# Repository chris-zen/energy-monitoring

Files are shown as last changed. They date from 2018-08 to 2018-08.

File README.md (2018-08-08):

# energy-monitoring

Source for my home's energy monitoring system

- [arduino](arduino) contains the firmware for an Arduino UNO board that samples voltage and intensity signals. Sampled data can be transferred to the computer through the USB port as a serial device.
- [python](python) contains Python code that knows how to read voltage and intensity data sampled with the Arduino board, how to filter and process the data to calculate Volts, Intensity and Power, and generate plots with [matplotlib](https://matplotlib.org/).
- [eagle](eagle) contains a hardware design for the final energy monitoring system, including the analog stages to prepare voltage and intensity signals to be sampled by the Arduino ADC (Unfinished).

# Blogs

* [My home energy monitoring vision](https://aloneinthehack.wordpress.com/2013/05/20/my-home-energy-monitoring-vision/)
* [First power measurements](https://aloneinthehack.wordpress.com/2013/04/27/first-power-measurements/)
* [Starting to explore OpenEnergyMonitor.org](https://aloneinthehack.wordpress.com/2013/04/07/starting-to-explore-openenergymonitor-org/)

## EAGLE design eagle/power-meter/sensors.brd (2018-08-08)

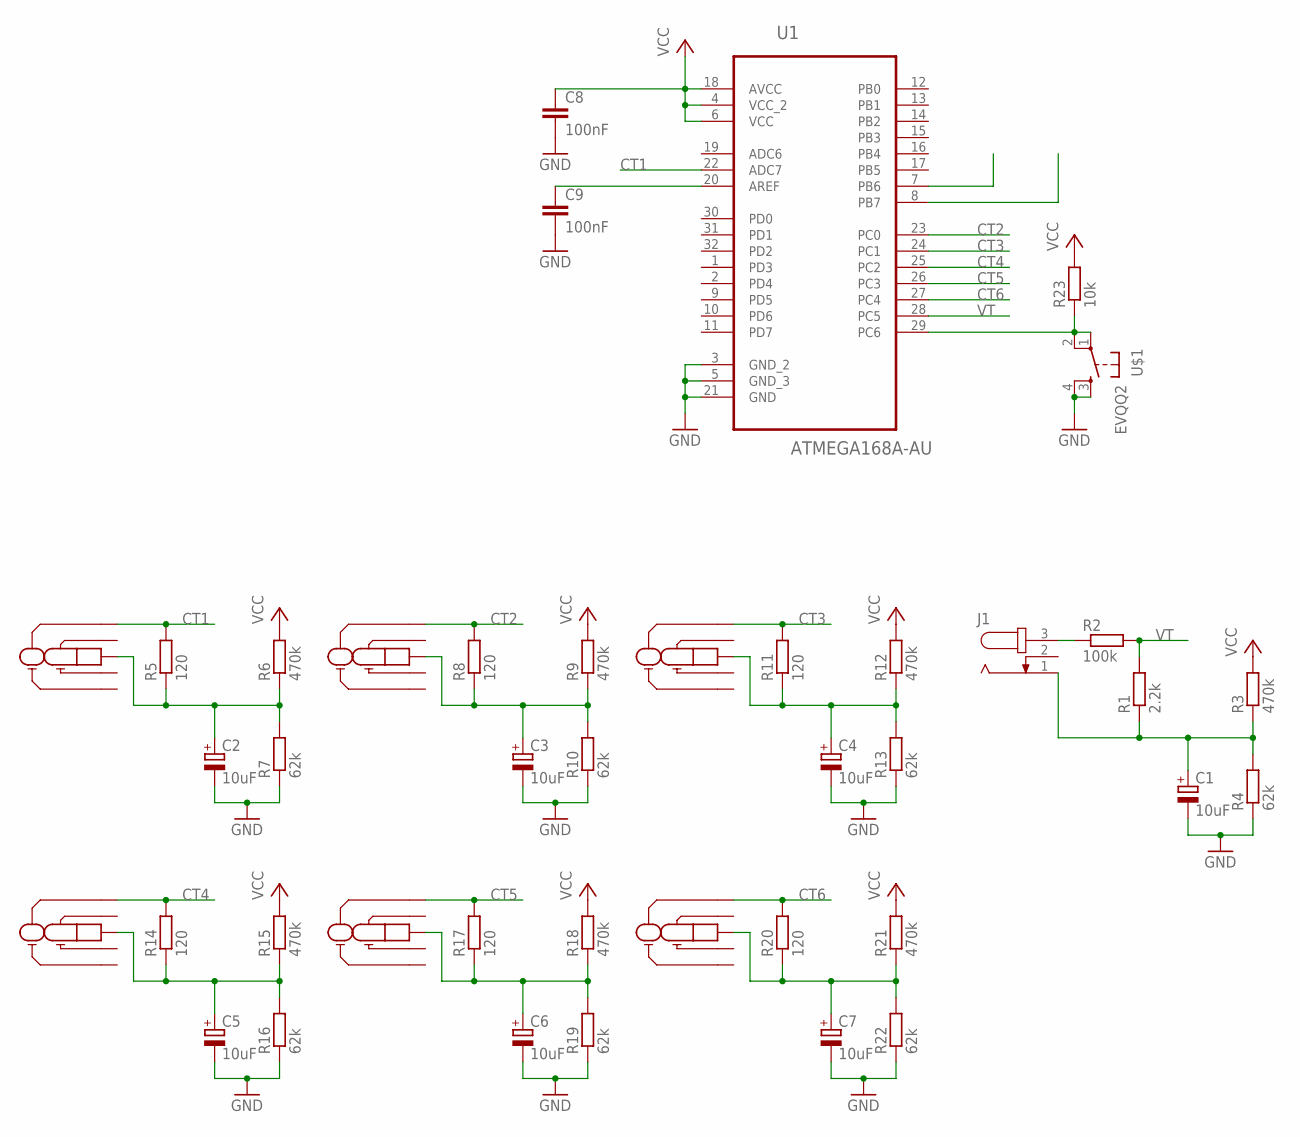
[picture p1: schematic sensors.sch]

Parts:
C1, C2, C3, C4, C5, C6, C7: 10uF; 153CLV-0405
C8, C9: 100nF; C1206
J1: JACK-PLUG0; SPC4077
JC1: 15428/BT
JC2, JC3, JC4, JC5, JC6: 15428/BT; 15428/BT@1
R1: 2.2k; R1206
R2: 100k; R1206
R3, R6, R9, R12, R15, R18, R21: 470k; R1206
R4, R7, R10, R13, R16, R19, R22: 62k; R1206
R5, R8, R11, R14, R17, R20: 120; R1206
R23: 10k; R1206
U1: ATMEGA168A-AU; QFP80P900X900X120-32N
U$1: EVQQ2

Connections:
AREF: C9.1, U1.20 (AREF)
CT1: JC1.P2, R5.2, U1.22 (ADC7)
CT2: JC2.P2, R8.2, U1.23 (PC0)
CT3: JC3.P2, R11.2, U1.24 (PC1)
CT4: JC4.P2, R14.2, U1.25 (PC2)
CT5: JC5.P2, R17.2, U1.26 (PC3)
CT6: JC6.P2, R20.2, U1.27 (PC4)
GND: C1.-, C2.-, C3.-, C4.-, C5.-, C6.-, C7.-, C8.2, C9.2, R4.1, R7.1, R10.1, R13.1, R16.1, R19.1, R22.1, U1.3 (GND_2), U1.5 (GND_3), U1.21 (GND), U$1.3, U$1.4
unnamed: J1.3, R2.1
unnamed: C1.+, J1.1, R1.1, R3.1, R4.2
unnamed: C2.+, JC1.P1, R5.1, R6.1, R7.2
unnamed: C3.+, JC2.P1, R8.1, R9.1, R10.2
unnamed: C4.+, JC3.P1, R11.1, R12.1, R13.2
unnamed: C5.+, JC4.P1, R14.1, R15.1, R16.2
unnamed: C6.+, JC5.P1, R17.1, R18.1, R19.2
unnamed: C7.+, JC6.P1, R20.1, R21.1, R22.2
RESET: R23.1, U1.29 (PC6), U$1.1, U$1.2
VCC: C8.1, R3.2, R6.2, R9.2, R12.2, R15.2, R18.2, R21.2, R23.2, U1.4 (VCC_2), U1.6 (VCC), U1.18 (AVCC)
VT: R1.2, R2.2, U1.28 (PC5)

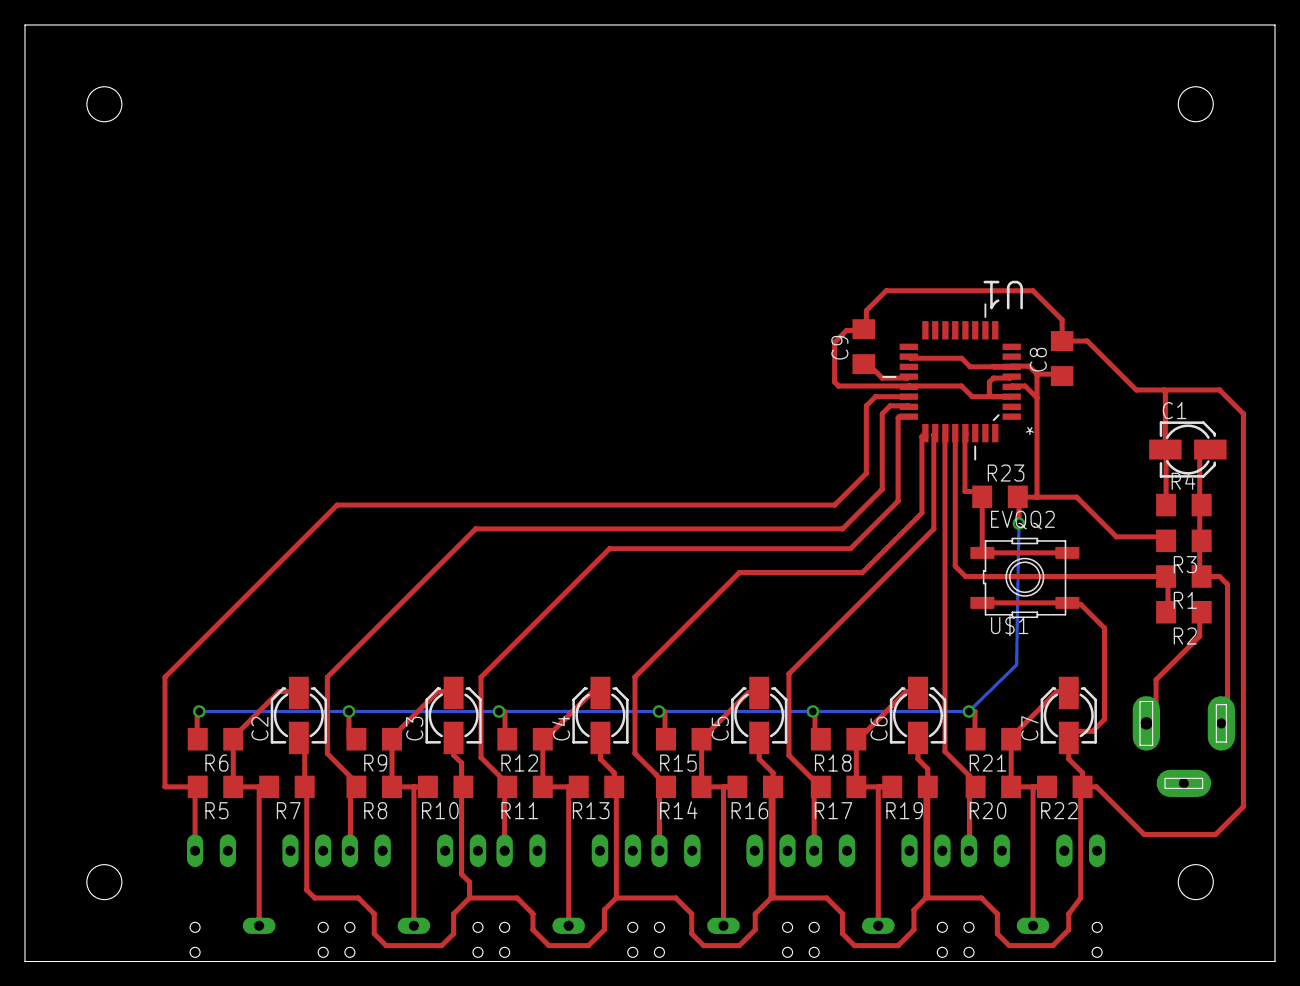
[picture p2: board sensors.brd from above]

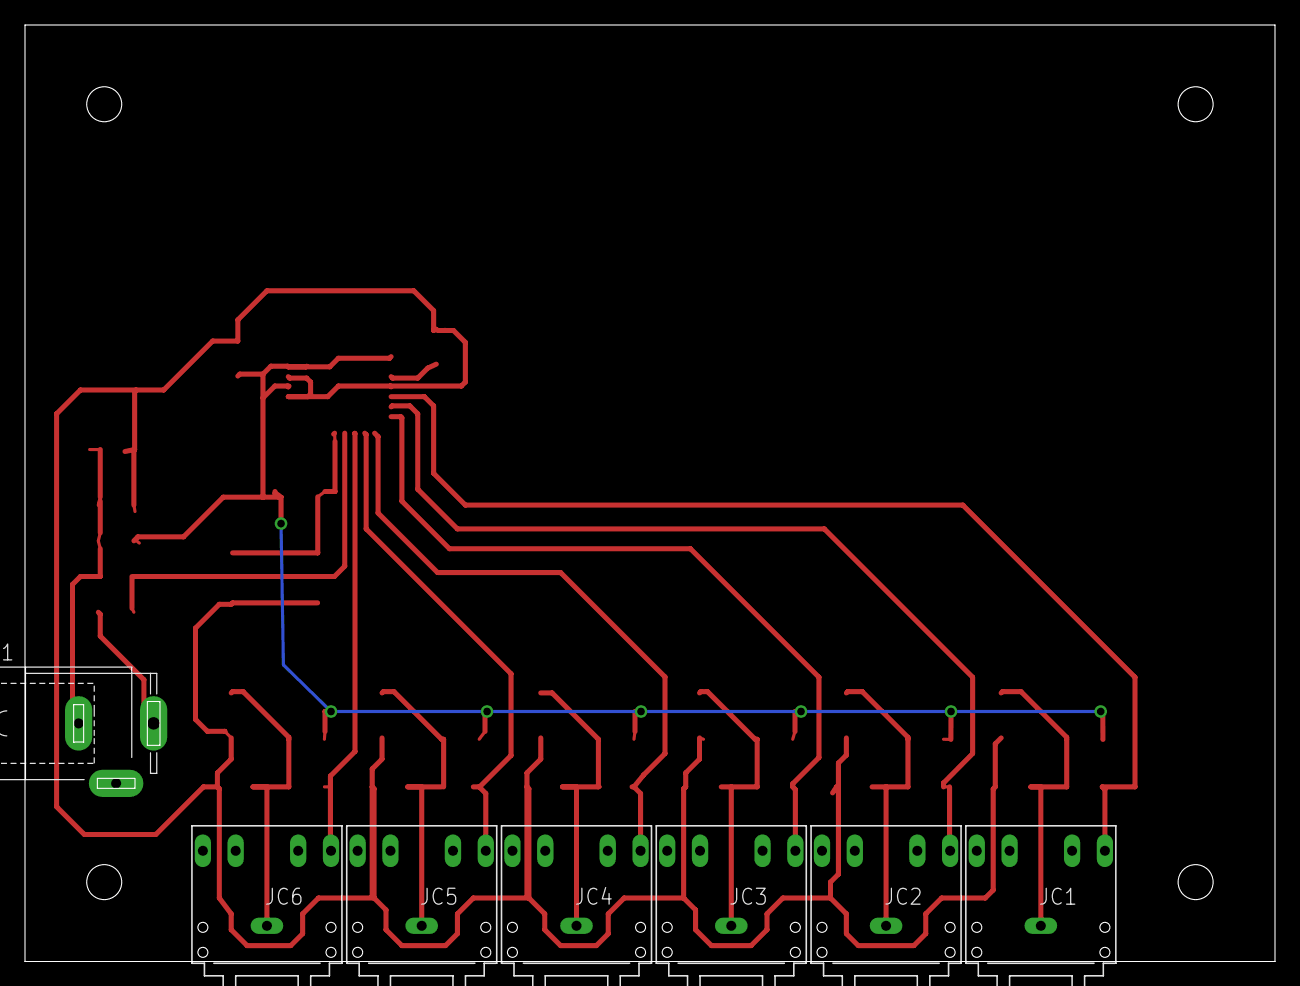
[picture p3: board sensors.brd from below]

Board: 2 copper layers, 100.0 x 74.9 mm, 41 parts (7 on the bottom side), 19 nets.

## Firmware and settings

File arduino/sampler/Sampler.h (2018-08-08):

// Sampling -----------------------------------------------------------

#define SAMPLING_BUFFER_SIZE 1200
#define DEFAULT_SAMPLING_FREQ 4000
#define MAX_SAMPLING_CHANNELS 2
#define NUM_ANALOG_PORTS 6
#define DEFAULT_TRIGGER_LEVEL 495
#define DEFAULT_TRIGGER_TIMEOUT 1000

typedef uint16_t sample_t;

class Sampler {
  private:
  
  byte buf[SAMPLING_BUFFER_SIZE];

  public:

  uint16_t num_samples;
  uint16_t max_samples;
    
  uint16_t freq;
  
  byte channels[MAX_SAMPLING_CHANNELS];
  byte num_channels;
  
  boolean trigger_enabled;
  byte trigger_channel;
  uint16_t trigger_level;
  uint16_t trigger_timeout; // miliseconds
  
  Sampler() {
    num_samples = 0;
    max_samples = 0; // unlimited
    freq = DEFAULT_SAMPLING_FREQ;
    channels[0] = 1;
    channels[1] = 2;
    num_channels = 2;
    trigger_enabled = true;
    trigger_channel = 1;
    trigger_level = DEFAULT_TRIGGER_LEVEL;
    trigger_timeout = DEFAULT_TRIGGER_TIMEOUT;
  }
  
  void set_freq(uint16_t f) {
    if (f == 0)
      f = DEFAULT_SAMPLING_FREQ;
    uint32_t period = 1000000L / f;
    freq = 1000000L / period;
  }
  
  void set_period(uint32_t period) {
    if (period == 0)
      period = 1000000L / DEFAULT_SAMPLING_FREQ;
    freq = 1000000L / period;
  }
  
  uint32_t get_period() {
    return 1000000L / freq; // in microseconds
  }

  void set_max_samples(uint16_t ms) {
    max_samples = ms;
  }

  void set_channels(byte nchan, byte chans[]) {
    memcpy(channels, chans, sizeof(channels));
    num_channels = nchan;
  }
  
  void send_samples() {
    byte* pv = buf;
    
    uint16_t last_value[MAX_SAMPLING_CHANNELS];
    memset(last_value, 512, sizeof(last_value));
    
    for (uint16_t i = 0; i < num_samples; i++) {
      for (byte j = 0; j < num_channels; j++) {
        
        //response.print(" [%hhx]", *pv);
        
        int16_t diff = ((byte) *pv++) & 0xFF;
        
        //response.print("{%x}", diff & 0x80);
        
        uint16_t value;
        if ((diff & 0x80) == 0) {
          volatile int16_t v = diff << 9;
          value = last_value[j] + (v >> 9);
        }
        else {
          volatile int16_t v = diff << 9;
          
          //response.print("[%hhx]", *pv);
          
          value = (v >> 1) | (byte) *pv++;
        }
        last_value[j] = value;
        
        if (j == 0)
          response.print("%u", value);
        else
          response.print(" %u", value);
      }
      response.println();
    }
  }
  
  void sample(const char* args) {
    byte* ps = buf; // current sample pointer
    byte* pc = buf; // current channel pointer
    byte* buf_end = &buf[SAMPLING_BUFFER_SIZE];
    
    uint32_t sampling_period = get_period();
  
    uint16_t last_value[MAX_SAMPLING_CHANNELS];
    memset(last_value, 512, sizeof(last_value));
    
    uint16_t value[MAX_SAMPLING_CHANNELS];
    memset(value, 0, sizeof(value));

    uint16_t max_samp = max_samples;
    if (max_samp == 0)
      max_samp = SAMPLING_BUFFER_SIZE / num_channels;
      
    num_samples = 0;
    
    // Change de ADC prescaler to CLK/16
    bitClear(ADCSRA, ADPS0);
    bitClear(ADCSRA, ADPS1);
    bitSet(ADCSRA, ADPS2) ;
    
    // Triggering
    
    if (trigger_enabled) {
      uint16_t trigger_pin = channels[trigger_channel];
      uint16_t last_value;
      uint16_t value = 1024;
      boolean triggered = false;
      uint32_t start_time = millis();
      while (!triggered && ((millis() - start_time) < trigger_timeout)) {
        last_value = value;
        value = analogRead(trigger_pin);
        triggered = (last_value <= trigger_level && value >= trigger_level);
      }
      /*if (!triggered) {
        response.error("TRIGGER TIMEOUT");
        return;
      }*/
    }
    
    // Sampling
    
    uint32_t max_time = 0;
    uint32_t start_time = micros();
    uint32_t elapsed_time = start_time;
    
    while (pc < buf_end && num_samples < max_samp) {
      
      // Read sample for all the channels
      for (byte j = 0; j < num_channels; j++)
        value[j] = analogRead(channels[j]);
      
      // Compress and store information
      byte j = 0;
      while (j < num_channels && pc < buf_end) {
        uint16_t v = value[j];
        int16_t diff = v - last_value[j];
        //response.print(" [%u - %u = %i]", v, last_value[j], diff);
        last_value[j] = v;
        if (diff >= -(1 << (7 - 1)) && diff <= ((1 << (7 - 1)) - 1)) { // -2**(n-1) <= value <= 2**(n-1) - 1
          *pc++ = (byte) (diff & 0x7F);
          j++;
        }
        else {
          *pc++ = (byte) (((v >> 8) & 0x7F) | 0x80);
           if (pc < buf_end) {
             *pc++ = (byte) (v & 0xFF);
             j++;
           }
           else
             pc++;
        }
      }
      //response.println();
      if (j <= num_channels && pc <= buf_end) {
        ps = pc;
        num_samples++;
      }

      // Wait until the period time ends
      max_time += sampling_period;
      elapsed_time = micros() - start_time;
      while (elapsed_time < max_time)
        elapsed_time = micros() - start_time;
    }
    
    // Response
    
    uint16_t f = 1000000L * num_samples / elapsed_time;
    uint32_t period = 1000000L / f;
    
    response.ok("%u %hhu %u %lu", num_samples, num_channels, f, period);
    
    if (*args == 'R')
      send_samples();
  }
  
  /*void normal_dist(const char* args) {
    uint32_t sum[num_channels];
    uint32_t sum_sqr[num_channels];
    memset(sum, 0, sizeof(sum));
    memset(sum_sqr, 0, sizeof(sum_sqr));
    
    sample_t* bp = buf;
    for (uint16_t i = 0; i < num_samples; i++) {
      for (byte j = 0; j < num_channels; j++) {
        uint16_t value = *bp++;
        sum[j] += value;
        sum_sqr[j] += value * value;
      }
    }
    
    response.ok("%u %hhu", num_samples, num_channels);
    
    uint16_t N = num_samples;
    float inv_N = 1.0f / N;
    for (byte j = 0; j < num_channels; j++) {
      response.print("%hhu", j);
      char s[10];
      float mean = sum[j] * inv_N;
      dtostrf(mean, 1, 2, s);
      response.print(" %s", s);
      float sd = sqrt((N * sum_sqr[j]) - sum[j] * sum[j]) / N;
      dtostrf(sd, 1, 2, s);
      response.println(" %s", s);
    }
  }*/

};

Sampler sampler;

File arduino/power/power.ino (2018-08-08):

#include <stdint.h>
#include <avr/pgmspace.h>

// Workaround for http://gcc.gnu.org/bugzilla/show_bug.cgi?id=34734 
#ifdef PROGMEM 
#undef PROGMEM 
#define PROGMEM __attribute__((section(".progmem.data"))) 
#endif

#include "Stream.h"

#include "Command.h"
#include "Response.h"
#include "Sampler.h"
#include "PowerCalc.h"

Command command = Command(&Serial);

Response response = Response(&Serial);

Sampler sampler;

// power ------------------------------------------------------------

#define DEFAULT_MAX_CICLES 20

uint8_t max_cicles = DEFAULT_MAX_CICLES;

PowerCalc power = PowerCalc(185, -1.0, 61.5);

uint16_t calc_power(Sampler& sampler, PowerCalc& power, uint8_t max_cicles, uint32_t max_time) {

  sampler.fast_prescaler();
  
  power.reset();
  
  uint16_t vcc = sampler.read_vcc();
  power.set_vcc(vcc);
  
  //response.debug("vcc: %u", vcc);

  uint8_t cicles = 0;

  uint32_t elapsed_time = 0;
  
  boolean triggered = sampler.trigger();
  
  while (cicles < max_cicles && elapsed_time < max_time) {

    power.compute_sample(
      sampler.get_v(),
      sampler.get_i());

	elapsed_time = micros() - sampler.get_start_time();
	
    triggered = sampler.sample();

    if (triggered) {
      cicles++;
    }
  }
  
  power.compute_total();
  
  uint16_t f = 1000000L * (uint64_t) power.get_num_samples() / elapsed_time;

  return f;
}

// config -----------------------------------------------------------

#define CONF_FREQ              1
#define CONF_PERIOD            2
#define CONF_TRIGGER           3
#define CONF_CICLES            4
#define CONF_PHCAL             5

#define CONF_NUM_PARAMS        5

#define CONF_NAME_MAX_SIZE 16

char conf_name_buf[CONF_NAME_MAX_SIZE];

const char conf_name_freq[] PROGMEM = "freq";
const char conf_name_period[] PROGMEM = "period";
const char conf_name_trigger[] PROGMEM = "trigger";
const char conf_name_cicles[] PROGMEM = "cicles";
const char conf_name_phcal[] PROGMEM = "phcal";

PGM_P const conf_name[] PROGMEM = {
  conf_name_freq,
  conf_name_period,
  conf_name_trigger,
  conf_name_cicles,
  conf_name_phcal
};

const char* get_conf_name(byte index) {
  strncpy_P(conf_name_buf, (PGM_P)pgm_read_word(&(conf_name[index - 1])), sizeof(conf_name_buf));
  return conf_name_buf;
}

byte get_conf_name_index(const char* name) {
  byte i = 0;
  byte param = atoi(name);
  while (param == 0 && i < CONF_NUM_PARAMS) {
    if (strncmp_P(name, (PGM_P)pgm_read_word(&(conf_name[i])), CONF_NAME_MAX_SIZE) == 0)
      param = i + 1;
    i++;
  }
  return param;
}

void substrn(char* dst, size_t n, const char* src, const char* src_end) {
  char* dst_end = dst + n;
  char* dp = dst;
  for (const char* sp = src; sp != src_end && dp != dst_end; sp++, dp++)
    *dp = *sp;
  *dp = 0;
}

void byte_array_string(char* s, size_t n, byte v[], int len, const char* sep=",") {
  char* sp = s;
  char* slast = s + n;
  if (len > 0) {
    sp += snprintf(sp, slast - sp, "%hhu", v[0]);
    for (int i = 1; i < len && sp < slast; i++) {
      sp += snprintf(sp, slast - sp, "%s%hhu", sep, v[i]);
    }
  }
  sp = min(sp, slast - 1);
  *sp = 0;
}

void config_get(byte param) {
  switch (param) {
    case CONF_FREQ:
      response.ok("%u", sampler.get_freq());
    break;
    case CONF_PERIOD:
      response.ok("%lu", sampler.get_period());
    break;
    case CONF_TRIGGER:
      response.ok("%u %lu", sampler.get_trigger_level(), sampler.get_trigger_timeout());
    break;
    case CONF_CICLES:
      response.ok("%hhu", max_cicles);
    break;
    case CONF_PHCAL:
      response.ok("%d", (int16_t)(power.get_phcal() * 1000.f));
    break;
  }
}

void config_set(byte param, char* val) {
  switch (param) {
    case CONF_FREQ:
      sampler.set_freq(atoi(val));
      response.ok("%u %lu", sampler.get_freq(), sampler.get_period());
    break;
    case CONF_PERIOD:
      sampler.set_period(atol(val));
      response.ok("%lu %u", sampler.get_period(), sampler.get_freq());
    break;
    case CONF_TRIGGER:
      {
        char* token = strtok(val, " ,");
        if (token != NULL && strlen(token) > 0) {
          byte level = atoi(token);
          if (level > 1023)
            level = sampler.get_trigger_level();
          uint32_t timeout = sampler.get_trigger_timeout();
          token = strtok(NULL, " ,");
          if (token != NULL && strlen(token) > 0)
            timeout = atoi(token);
          sampler.set_trigger(level, timeout);
        }
        response.ok("%u %lu", sampler.get_trigger_level(), sampler.get_trigger_timeout());
      }
    break;
    case CONF_CICLES:
      max_cicles = atol(val);
      if (max_cicles == 0)
        max_cicles = 1;
      else if (max_cicles > 200)
        max_cicles = 200;
      response.ok("%hhu", max_cicles);
    break;
    case CONF_PHCAL:
      power.set_phcal(atol(val) / 1000.0f);
      response.ok("%i", (int16_t)(power.get_phcal() * 1000.f));
    break;
  }
}

void config(const char* args) {
    
  if (strlen(args) == 0) {
    response.ok("%u", CONF_NUM_PARAMS);
    response.println("%s=%u", get_conf_name(CONF_FREQ), sampler.get_freq());
    response.println("%s=%li", get_conf_name(CONF_PERIOD), sampler.get_period());
    response.println("%s=%u,%lu", get_conf_name(CONF_TRIGGER), sampler.get_trigger_level(), sampler.get_trigger_timeout());
    response.println("%s=%hhu", get_conf_name(CONF_CICLES), max_cicles);
    response.println("%s=%i", get_conf_name(CONF_PHCAL), (int16_t)(power.get_phcal() * 1000.f));
  }
  else {
    const char* name = args;
    char* sep = strchr(args, '=');
    if (sep != NULL) {
      substrn(conf_name_buf, CONF_NAME_MAX_SIZE, args, sep); // memcpy(conf_name_buf, args, sep - args);
      name = conf_name_buf;
    }
    
    byte param = get_conf_name_index(name);
    
    if (param == 0) {
      response.error("Unknown: %s", name);
      return;
    }
      
    if (sep == NULL)     // get
      config_get(param);
    else                 // set
      config_set(param, ++sep);
  }
}

// -----------------------------------------------------------

int free_mem() {  
  extern int __heap_start, *__brkval;
  int v;
  return (int) &v - (__brkval == 0 ? (int) &__heap_start : (int) __brkval);  
}

void setup() {
  Serial.begin(115200);

  while (Serial.available() > 0)
    Serial.read();
    
  sampler.set_freq(DEFAULT_SAMPLING_FREQ);
  
  //Serial.print('>'); Serial.println(free_mem());
  
  // warm up the power calculator
  calc_power(sampler, power, 20, 400000);
}

void loop() {
  
  const char* cmd = command.read();
  const char* ch = cmd;
  
  switch (*ch++) {
    case 'C': // Configuration
      config(ch);
    break;
    
    case 'V':
      response.ok("%lu", sampler.read_vcc());
    break;
    
    case 'F':
      response.ok("%i", free_mem());
    break;
    
    case 'P':
      {
		  uint16_t freq = calc_power(sampler, power, max_cicles, (max_cicles + 1) * 20000L);
		  
		  response.ok("%d %d %d %d %d %u",
		    (uint16_t) (power.get_v_rms() * 100.0f),
		    (uint16_t) (power.get_i_rms() * 100.0f),
		    (uint16_t) power.get_real_power(),
		    (uint16_t) power.get_apparent_power(),
		    (uint16_t) (power.get_power_factor() * 10000.0f),
		    freq);
		  /*Serial.print(power.get_v_rms());
		  Serial.print(" ");
		  Serial.print(power.get_i_rms());
		  Serial.print(" ");
		  Serial.print(power.get_real_power());
		  Serial.print(" ");
		  Serial.print(power.get_apparent_power());
		  Serial.print(" ");
		  Serial.print(power.get_power_factor());
		  Serial.println();*/
      }
    break;
    
    case 'A':
      response.ok("PowerMonitor 0.1");
    break;
    
    default:
      response.error("Unknown: %s", cmd);
  }
}

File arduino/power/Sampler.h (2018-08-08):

// Sampling -----------------------------------------------------------

#define DEFAULT_SAMPLING_FREQ 4000
#define NUM_ANALOG_PORTS 6
#define DEFAULT_TRIGGER_LEVEL 495
#define DEFAULT_TRIGGER_TIMEOUT 1000000

typedef uint16_t sample_t;

class Sampler {
  private:
  
  uint16_t freq;
  uint32_t period;
  
  uint8_t v_pin;
  uint8_t i_pin;

  uint16_t trigger_level;
  uint32_t trigger_timeout;

  uint32_t start_time;
  uint32_t total_time;
  uint32_t elapsed_time;

  uint16_t last_v_value;

  uint16_t v_value;
  uint16_t i_value;

  public:

  static const uint16_t TRIGGER_TIMEOUT = 0xFFFF;

  Sampler() {
    freq = DEFAULT_SAMPLING_FREQ;
    v_pin = 2;
    i_pin = 1;
    trigger_level = DEFAULT_TRIGGER_LEVEL;
    trigger_timeout = DEFAULT_TRIGGER_TIMEOUT;
    start_time = 0;
  }
  
  void set_freq(uint16_t f) {
    if (f == 0)
      f = DEFAULT_SAMPLING_FREQ;
    period = 1000000L / f;
    freq = 1000000L / period;
  }

  uint16_t get_freq() {
    return freq;
  }
  
  void set_period(uint32_t period) {
    if (period == 0)
      period = 1000000L / DEFAULT_SAMPLING_FREQ;
    this->period = period;
    freq = 1000000L / period;
  }
  
  uint32_t get_period() {
    //return 1000000L / freq; // in microseconds
    return period;
  }

  void set_pins(uint8_t vpin, uint8_t ipin) {
    v_pin = vpin;
    i_pin = ipin;
  }

  uint8_t get_v_pin() {
    return v_pin;
  }

  uint8_t get_i_pin() {
    return i_pin;
  }

  void set_trigger(uint16_t level, uint16_t timeout) {
    trigger_level = level;
    trigger_timeout = timeout;
  }

  uint16_t get_trigger_level() {
    return trigger_level;
  }

  uint32_t get_trigger_timeout() {
    return trigger_timeout;
  }

  uint16_t get_v() {
    return v_value;
  }

  uint16_t get_i() {
    return i_value;
  }
  
  uint32_t get_start_time() {
    return start_time;
  }
  
  uint32_t get_elapsed_time() {
    return elapsed_time;
  }

  void fast_prescaler() {
    // Change de ADC prescaler to CLK/16
    bitClear(ADCSRA, ADPS0);
    bitClear(ADCSRA, ADPS1);
    bitSet(ADCSRA, ADPS2) ;
  }

  uint16_t read_vcc() {
    #if defined(__AVR_ATmega168__) || defined(__AVR_ATmega328__) || defined (__AVR_ATmega328P__)
    ADMUX = _BV(REFS0) | _BV(MUX3) | _BV(MUX2) | _BV(MUX1);  
    #elif defined(__AVR_ATmega32U4__) || defined(__AVR_ATmega1280__) || defined(__AVR_ATmega2560__)
    ADMUX = _BV(REFS0) | _BV(MUX4) | _BV(MUX3) | _BV(MUX2) | _BV(MUX1);
    #elif defined (__AVR_ATtiny24__) || defined(__AVR_ATtiny44__) || defined(__AVR_ATtiny84__)
    ADMUX = _BV(MUX5) | _BV(MUX0);
    #elif defined (__AVR_ATtiny25__) || defined(__AVR_ATtiny45__) || defined(__AVR_ATtiny85__)
    ADMUX = _BV(MUX3) | _BV(MUX2);
    #endif

    delay(2);       // Wait for Vref to settle
    ADCSRA |= _BV(ADSC);      // Convert
    while (bit_is_set(ADCSRA, ADSC));
    
    uint32_t result = ADCL;
    result |= ADCH << 8;
    result = 1126400L / result;   //1100 mV * 1024 ADC steps http://openenergymonitor.org/emon/node/1186
    return result;
  }

  boolean trigger() {
    total_time = elapsed_time = 0;
    v_value = 1024;
    boolean triggered = false;
    start_time = micros();
    uint32_t timeout_start = start_time;
    while (!triggered && ((start_time - timeout_start) < trigger_timeout)) {
      last_v_value = v_value;
      start_time = micros();
      v_value = analogRead(v_pin);
      i_value = analogRead(i_pin);
      triggered = (last_v_value < trigger_level && v_value >= trigger_level);
    }

    return triggered;
  }

  boolean sample() {
    last_v_value = v_value;
    
    // Wait until the period time ends
    /*total_time += get_period();
    elapsed_time = micros() - start_time;
    while (elapsed_time < total_time)
      elapsed_time = micros() - start_time;*/

	//i_value = analogRead(i_pin);
    v_value = analogRead(v_pin);
    i_value = analogRead(i_pin);

    return last_v_value < trigger_level && v_value >= trigger_level;
  }

};

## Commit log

2013-04-27 Small changes in power_scope for video recording
2013-04-28 Modularizing sampler.ino
2013-05-03 arduino power node started
2013-05-03 power calculation works
2013-05-05 Power Analyzer created
2013-05-25 Fixed a bug with last value in lp and hp filters in signalv
2013-05-25 Sampler adapted to work with reference voltage of 1.1V
2013-05-25 plot_score works with reference voltage of 1.1V and shows ADV input voltage instead of steps
2013-05-25 Working on the power-meter schemas
    [sensors.brd, sensors.sch]
2013-06-04 Common Eagle library created. Working on power-node schematics
    [sensors.brd, sensors.sch]
2013-06-10 Working on power-monitor PCB
    [sensors.brd, sensors.sch]
